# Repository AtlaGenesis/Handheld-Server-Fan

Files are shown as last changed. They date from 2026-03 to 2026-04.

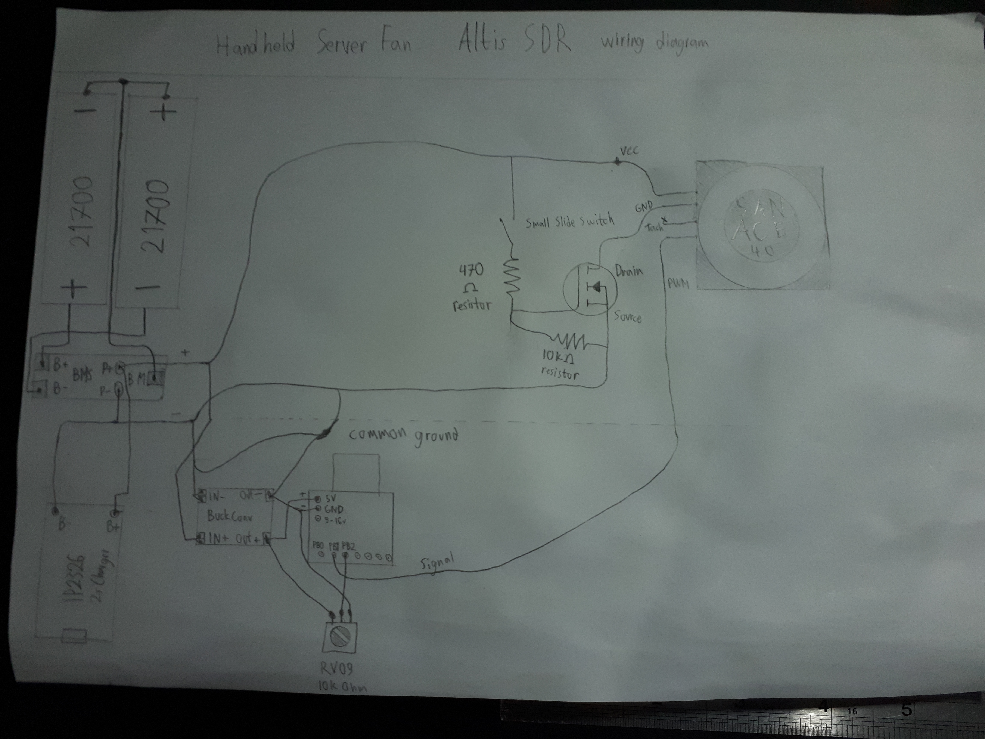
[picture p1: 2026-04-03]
Handheld Server Fan 8025/WiringDiagram.jpg

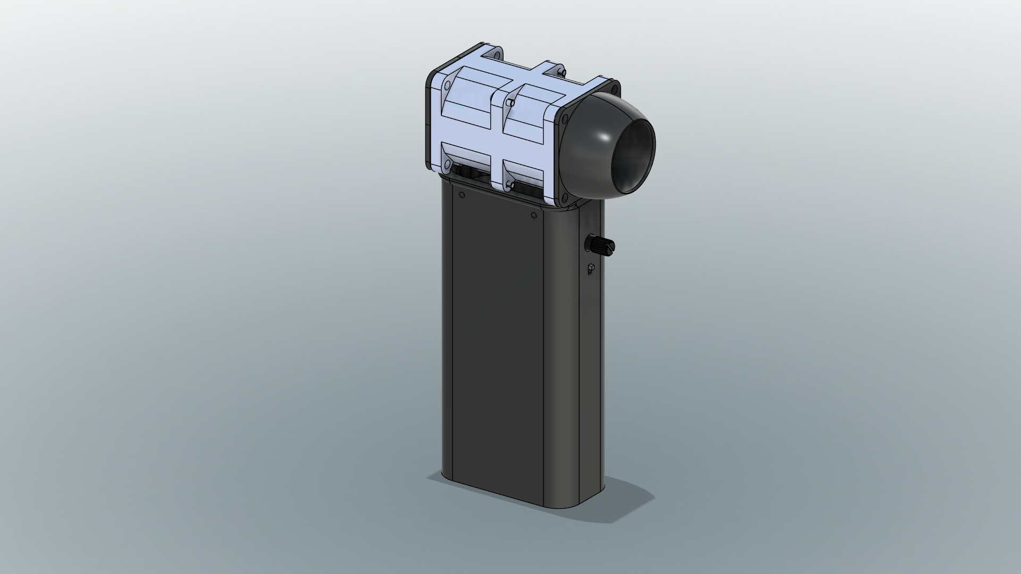
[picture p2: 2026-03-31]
Handheld Server Fan 8025/CAD files/Altis SDF.png

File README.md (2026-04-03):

# Handheld-Server-Fan
A Guide to Turn a 4056 Server Fan INTO A POWERFUL HANDHELD FAN!!

# Previews
### Fully assembled
Altis SDR 1
Altis SDR 2

### Everything fits inside the case



### Wiring Diagrammmmm
WiringDiagram

 I could NOT find anytools that's faster than drawing on paper, this one is better, AND I MADE SURE THAT EVERY COMPONENT IS THERE

# Features
The 4056 model lets for a much higher energy density, its counter rotating feature directs the airflow to be straight and improve static pressure
This fan has tens of thousands of rated usage, it can last way way longer than even the batteries (which already has a long lifetime)
The knob lets you adjust the speed based on your needs.
The type C charger lets you charge with your phone charger

# 3D printing things: 
- Print with the orientation the same as you see on the file!
- All printed using Black ASA/ABS
- All 0.4mm Nozzle
- All 0.2/0.16/0.12 Layer height
- All 40% infill
- All 6 or more Walls Perimeter
- Slow print speed
- Fan at 0%
- 50 degrees C enclosure (if you have)

# BOM:

1. Delta/San Ace/Sunon 40mm counter rotating
https://shopee.co.id/KIPAS-DELTA-4CM-GFB0412EHS-12V-1.82A-HIGH-SPEED-COPOTAN-SERVER-i.363566116.43973466943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"display_model_id"%3A271907539569%2C"model_selection_logic"%3A3%7D&sp_atk=1e666d0a-0986-4b60-ad5e-69f85a8b8641&xptdk=1e666d0a-0986-4b60-ad5e-69f85a8b8641

2. 2s 21700 5000mAh (M50LT)
https://shopee.co.id/LG-M50LT-BATERAI-21700-5000mAh-15A-HIGH-CAPACITY-INR21700M5OLT-i.457468239.27587381668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

3. IP2326 2s Charger 
https://shopee.co.id/IP2326-Step-Up-Battery-18650-Charger-Charging-2S-3S-BMS-With-Balance-1.5A-15Watt-Type-C-Battery-Charging-i.915347685.26127899926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

4. Buck converter to 5v
https://shopee.co.id/DC-DC-Buck-Step-Down-MP1584EN-3A-Power-Supply-Module-5–24V-ke-5V-3.3V-9V-12V-Fixed-Output-Syalis--i.16973105.41078075584?extraParams=%7B"display_model_id"%3A405440774976%2C"model_selection_logic"%3A3%7D&sp_atk=e4a32fa4-93ca-49dc-83f4-d6267a087d06&xptdk=e4a32fa4-93ca-49dc-83f4-d6267a087d06

5. ATtiny85 Digispark
https://shopee.co.id/Digispark-ATTINY85-kickstarter-usb-develoepment-board-arduino-uno-smd-etc-komputer-kabel-i.533505386.43503223452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

6. RV09 kc 20 10k Potentiometer
https://shopee.co.id/potensiometer-potentiometer-potensio-10k-rv09-12.5mm-RV-09-10-K-i.18663910.18844315772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

7. 2s BMS 8A
https://shopee.co.id/BMS-2S-8A-8.4V-Kecil-Lithium-Ion-Battery-Management-Protection-Board-i.189362216.23186933050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

8. 4x M2x8 (5 MOQ 18 cents total)
https://shopee.co.id/Baut-JP-M2x8-Stainless-304-Phillips-Head-Screw-M2*8-Sekrup-2mm-x-8mm-M2-Obeng-Plus-SS304-i.96037146.24243396278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

9. 10 set of m3x15 and m3 nut (12 cents total)
https://shopee.co.id/(10-SET)-MUR-BAUT-JP-M3X10-MUR-3MM-PANJANG-BAUT-10MM-i.1564064068.53701015197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

10. 4x M2 nut (20 MOQ, 18 cents total)
https://shopee.co.id/Tamiya-Silver-Nuts-M2-per-pcs-Mur-Silever-drat-2-mm-i.3086070.23315441929?extraParams=%7B"display_model_id"%3A98560920657%2C"model_selection_logic"%3A3%7D&sp_atk=bab32065-328e-44c7-bbca-39e35735ce33&xptdk=bab32065-328e-44c7-bbca-39e35735ce33

11. 4 Pin JST Connector (2 MOQ 48 cents total)
https://shopee.co.id/Socket-Kabel-JST-SM-4p-4-Pin-Wire-Sambungan-Konektor-Kabel-Male-Female-i.342972164.22755093244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"display_model_id"%3A138744600112%2C"model_selection_logic"%3A3%7D&sp_atk=18972638-1e2c-41c5-82aa-e6c268296418&xptdk=18972638-1e2c-41c5-82aa-e6c268296418

12. Small Slide Switch 
https://shopee.co.id/Slide-Switch-SPDT-1P2T-Saklar-Geser-Kecil-Mini-Toggle-3-Pin-PCB-4mm-i.1093272634.21085961858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

13. IRLZ44N Logic Level MOSFET (2 MOQ, 48 cents total)
https://shopee.co.id/MOSFET-IRLZ44N-TO-220-MOSFETs-IRL-Z44N-IRLZ-44-N-IRLZ-44N-i.65450634.23978897717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"display_model_id"%3A29726184959%2C"model_selection_logic"%3A2%7D&sp_atk=45c97864-0b0b-4591-b32a-47e699384358&xptdk=45c97864-0b0b-4591-b32a-47e699384358

14. 470 Ohm resistor
https://shopee.co.id/10X-RESISTOR-470-OHM-1-4W-1-METAL-FILM-i.1078675148.22483412828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

15. 10k resistor
https://shopee.co.id/Resistor-10000-10K-10-K-10000R-Ohm-1-4-W-5-5pcs-pack-i.14183026.5815556375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"display_model_id"%3A51160481603%2C"model_selection_logic"%3A2%7D&sp_atk=626e046e-cc68-442b-bbd6-a70bb2a84dc3&xptdk=626e046e-cc68-442b-bbd6-a70bb2a84dc3

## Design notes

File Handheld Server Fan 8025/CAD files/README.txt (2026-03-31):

The FIle that has "PREVIEW ONLY" has all of the components inside, including electronics and a simple model of the fan itself
While the FIle "PRINT USING THIS ORIENTATION" only have components mandatory to print, and lets you know which orientation of each component should be printed at

All printed using Black ASA/ABS
All 0.4mm Nozzle
All 0.2 Layer height
All 25% infill
All 6 or more Walls Perimeter
Slow print speed
Low or off fan

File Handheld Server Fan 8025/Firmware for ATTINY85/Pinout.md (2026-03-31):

5v - vcc
GND - GND
pot wiper - PB2
one of the pot side - vcc
the other side - gnd
pwm signal - PB1

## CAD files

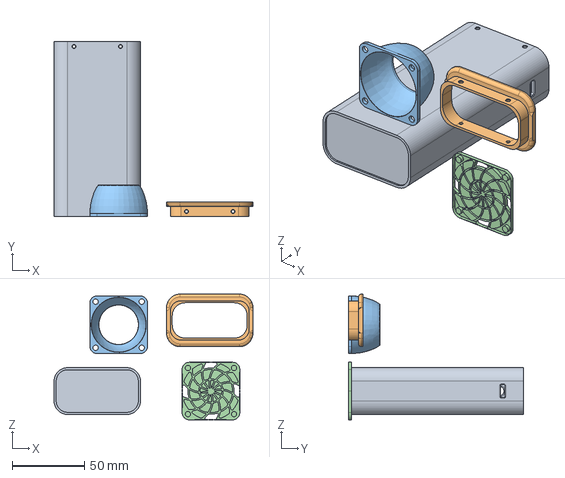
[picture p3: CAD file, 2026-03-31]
Handheld Server Fan 8025/CAD files/Altis SDR Full.step
138.0 x 121.5 x 87.3 mm

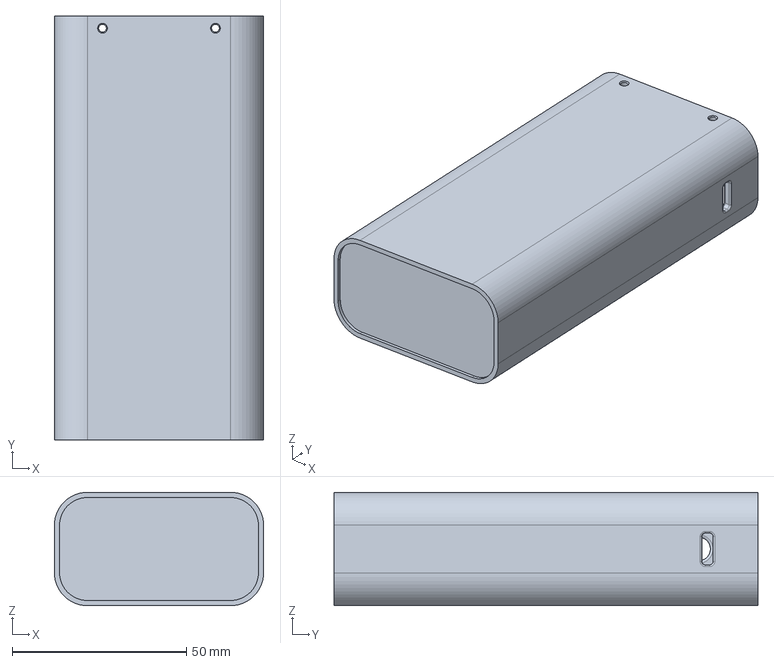
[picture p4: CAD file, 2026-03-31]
Handheld Server Fan 8025/CAD files/Altis SDF Case.step
60.0 x 121.5 x 32.5 mm

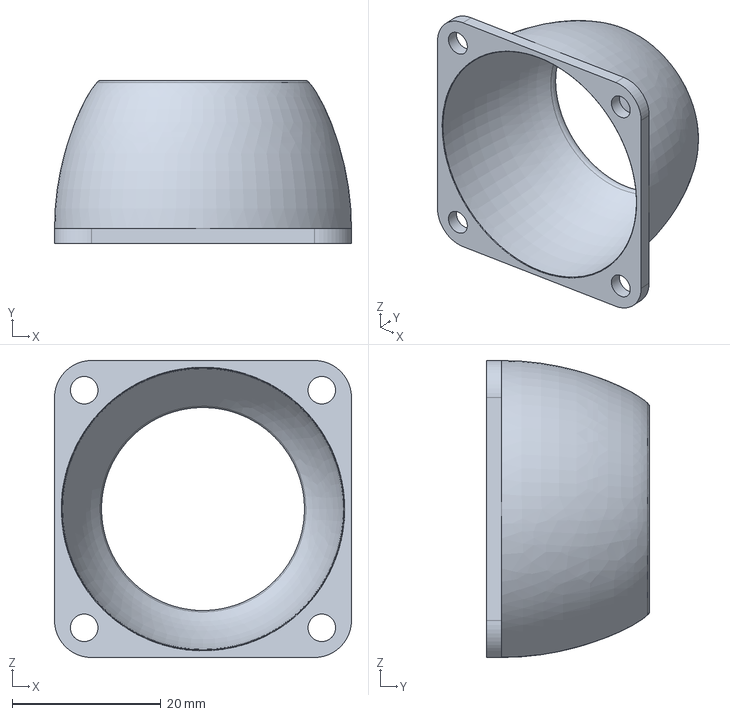
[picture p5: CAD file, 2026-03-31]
Handheld Server Fan 8025/CAD files/Altis SDF Nozzle.step
40.0 x 21.9 x 40.0 mm

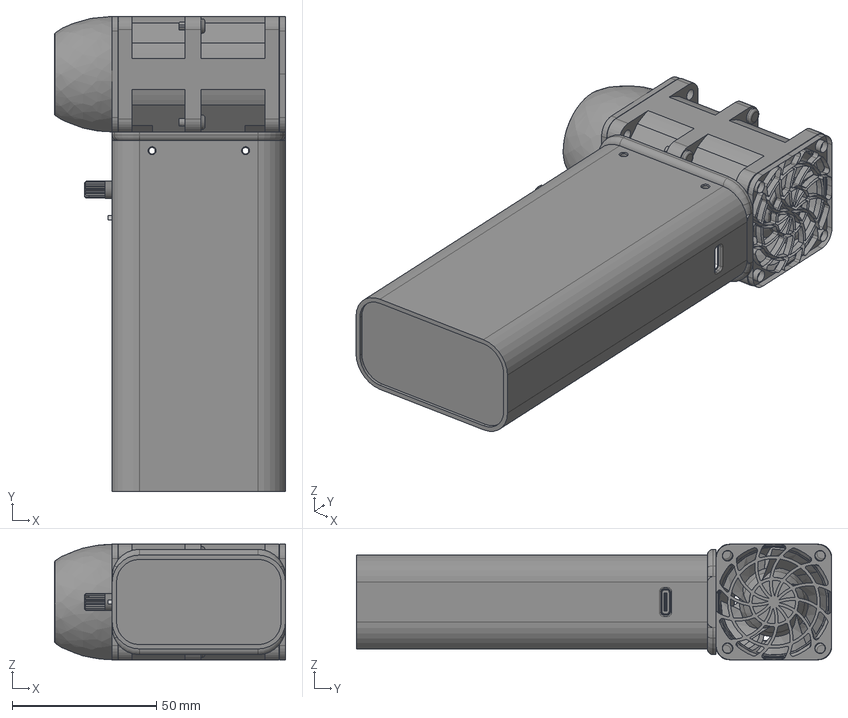
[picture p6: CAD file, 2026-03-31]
Handheld Server Fan 8025/CAD files/Altis SDF PREVIEW ONLY.step
79.9 x 164.5 x 40.0 mm
4056 Fan

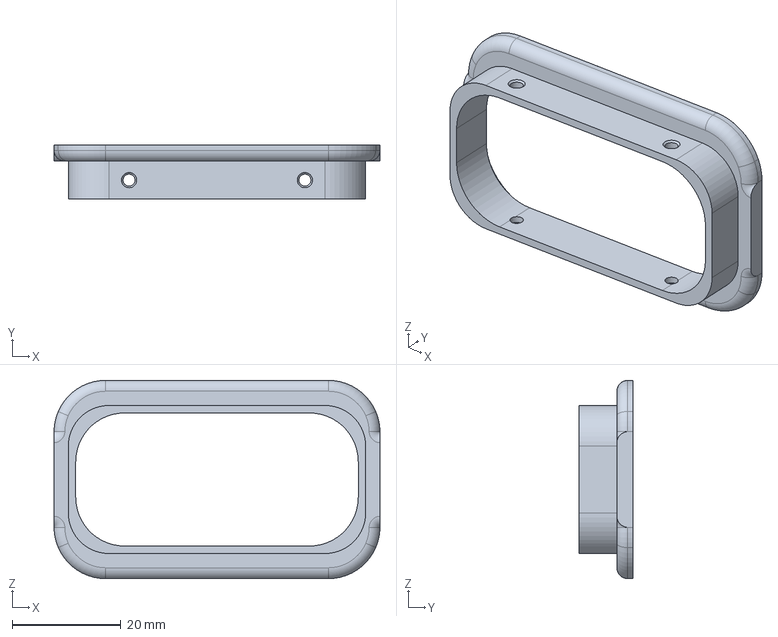
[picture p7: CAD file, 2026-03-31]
Handheld Server Fan 8025/CAD files/Altis SDF Bracket.step
60.0 x 10.0 x 36.5 mm

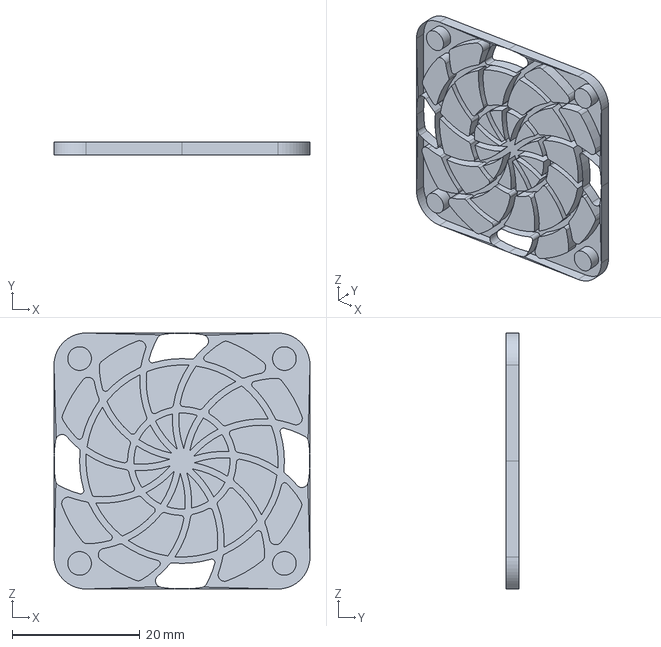
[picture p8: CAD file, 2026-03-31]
Handheld Server Fan 8025/CAD files/Altis SDF Fan Grill.step
40.0 x 2.00 x 40.0 mm

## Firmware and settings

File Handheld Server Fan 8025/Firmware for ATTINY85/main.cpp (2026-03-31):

// ATTINY85 PWM generator on PB1 (OC1A) at 25 kHz
// Potentiometer on PB2 (ADC1), mapped 25%..100% duty
// Startup behavior per spec with soft ramps

#define F_CPU 8000000UL  // CPU clock for delay timing; set to your fuse clock
#include <avr/io.h>
#include <util/delay.h>
#include <stdint.h>

// Timer1 runs from PLL (64 MHz) with prescaler /16 for 25 kHz
// fPWM = 64 MHz / (16 * (TOP + 1)) => TOP = 159 for 25 kHz
#define PWM_TOP 159

#define ADC_MIN_THRESHOLD 8   // treat <= ~0.8% as "minimum" (noise guard)
#define RAMP_STEP_MS 5         // ramp granularity

static void pwm_init(void);
static void adc_init(void);
static uint16_t adc_read(void);
static uint16_t adc_read_avg(uint8_t samples);
static uint8_t adc_to_duty(uint16_t adc);
static void pwm_set_duty(uint8_t duty_percent);
static void ramp_duty(uint8_t start, uint8_t end, uint16_t duration_ms);

int main(void) {
    pwm_init();
    adc_init();

    _delay_ms(10);       // allow ADC to settle
    (void)adc_read();    // discard first conversion

    uint16_t adc_start = adc_read_avg(8);
    uint8_t target = adc_to_duty(adc_start);

    if (adc_start <= ADC_MIN_THRESHOLD) {
        pwm_set_duty(0);
        ramp_duty(0, 25, 750);   // 0% -> 25% in 0.75 s
        target = 25;
    } else {
        pwm_set_duty(25);
        ramp_duty(25, target, 1000); // 25% -> target in 1 s
    }

    uint8_t current = target;

    while (1) {
        uint16_t adc = adc_read_avg(4);
        uint8_t duty = adc_to_duty(adc);

        if (duty != current) {
            pwm_set_duty(duty);
            current = duty;
        }

        _delay_ms(5);  // modest update rate to reduce ADC jitter
    }
}

// ------------------------- PWM -------------------------

static void pwm_init(void) {
    DDRB |= (1 << PB1);   // PB1 as output (OC1A)
    PORTB &= ~(1 << PB1); // ensure low at start

    // Enable PLL (64 MHz) and route to Timer1
    PLLCSR = (1 << PLLE);
    while (!(PLLCSR & (1 << PLOCK))) {
        // wait for PLL lock
    }
    PLLCSR |= (1 << PCKE);

    // Set PWM top and initialize duty
    OCR1C = PWM_TOP;
    OCR1A = 0;

    // Fast PWM on OC1A, non-inverting, prescaler /16
    // Prescaler bits for /16: CS12 and CS10 set (per ATtiny85 Timer1)
    TCCR1 = (1 << PWM1A) | (1 << COM1A1) | (1 << CS12) | (1 << CS10);
}

static void pwm_set_duty(uint8_t duty_percent) {
    if (duty_percent == 0) {
        // Disconnect OC1A and drive low for true 0%
        TCCR1 &= ~((1 << COM1A1) | (1 << COM1A0));
        PORTB &= ~(1 << PB1);
        OCR1A = 0;
        return;
    }

    // Ensure OC1A connected in non-inverting mode
    TCCR1 = (TCCR1 & ~((1 << COM1A1) | (1 << COM1A0))) | (1 << COM1A1);

    uint16_t compare = ((uint32_t)(PWM_TOP + 1) * duty_percent) / 100;
    if (compare == 0) compare = 1;
    if (compare > PWM_TOP) compare = PWM_TOP;

    OCR1A = (uint8_t)compare;
}

// ------------------------- ADC -------------------------

static void adc_init(void) {
    // ADC1 (PB2), VCC as reference
    ADMUX = (1 << MUX0);  // MUX=001 for ADC1
    ADCSRA = (1 << ADEN)  // enable ADC
           | (1 << ADPS2) | (1 << ADPS1) | (1 << ADPS0); // prescaler /128
    DIDR0 |= (1 << ADC1D); // disable digital input on ADC1
}

static uint16_t adc_read(void) {
    ADCSRA |= (1 << ADSC);
    while (ADCSRA & (1 << ADSC)) {
        // wait for conversion
    }
    return ADC;
}

static uint16_t adc_read_avg(uint8_t samples) {
    uint32_t acc = 0;
    for (uint8_t i = 0; i < samples; i++) {
        acc += adc_read();
    }
    return (uint16_t)(acc / samples);
}

static uint8_t adc_to_duty(uint16_t adc) {
    // Map 0..1023 -> 25..100
    uint32_t duty = 25 + ((uint32_t)adc * 75) / 1023;
    if (duty > 100) duty = 100;
    return (uint8_t)duty;
}

// ------------------------- Ramping -------------------------

static void ramp_duty(uint8_t start, uint8_t end, uint16_t duration_ms) {
    if (duration_ms == 0 || start == end) {
        pwm_set_duty(end);
        return;
    }

    uint16_t steps = duration_ms / RAMP_STEP_MS;
    if (steps == 0) steps = 1;

    int16_t delta = (int16_t)end - (int16_t)start;

    for (uint16_t i = 0; i < steps; i++) {
        uint8_t duty = (uint8_t)(start + ((int32_t)delta * i) / steps);
        pwm_set_duty(duty);
        _delay_ms(RAMP_STEP_MS);
    }

    pwm_set_duty(end);
}

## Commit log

2026-02-07 Add BOM section to README
    Added Bill of Materials (BOM) for the handheld fan project.
2026-02-08 Enhance README with server fan benefits and BOM links
    Expanded the README with additional information on the efficiency and advantages of using a server fan for handheld applications. Included links to components for building the handheld fan.
2026-02-08 Revise README to highlight power and efficiency
    Updated the description of the handheld fan project to emphasize power and efficiency over transparency.
2026-02-08 Enhance README with features and comparisons
    Added features section detailing the advantages of the handheld fan, including power consumption, efficiency, and design benefits. Expanded on the comparison between server fans and standard PC fans.
2026-02-16 Revise README to remove unnecessary fan comparison details
    Removed redundant section discussing the efficiency and advantages of server fans compared to standard PC fans.
2026-02-16 Add JST Connector to the README
2026-02-17 Add 3D printing instructions to README
    Added 3D printing instructions including orientation, infill, nozzle, layer height, and color.
2026-02-17 Add fully assembled image to README
    Added image of fully assembled product to README.
2026-02-18 Revise 3D printing parameters in README
    Updated 3D printing specifications for better clarity.
2026-03-16 Change fan model from 8025 to 4056
    Updated fan model references and specifications in the README.
2026-03-31 Update README with wiring diagram and component details
    Added wiring diagram section and updated component list. I need 2 mr days for wiring diagram
2026-03-31 add files
    wiring diagram later
    [Altis SDF Bracket.step, Altis SDF Case.step, Altis SDF Fan Grill.step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]
2026-04-03 Update wiring diagram section in README
    Updated wiring diagram section with an image placeholder and revised text.
2026-04-03 Fix wiring diagram image in README
    Updated wiring diagram image link in README.
2026-04-03 wiring diagram
    IM SORRY I'M LATE BY A DAY
